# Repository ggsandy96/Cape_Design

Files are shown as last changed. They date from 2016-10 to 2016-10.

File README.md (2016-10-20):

# Cape_Design
The Cape for beagle bone has the options for ADC to BBB till 24V and an power controller circuit, with reverse polarity protection and over voltage protection. Apart from these, there was an interrupt generator, which generates an interrupt when the power goes off and BBB shifts to battery power

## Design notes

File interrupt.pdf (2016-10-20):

Installations:

1. sudo apt-get install git
2. git clone https://github.com/derekmolloy/exploringBB.git
3. cd exploringBB/extras/kernel/gpio_test

Replace gpio_test.c with the new ‘gpio_test.c’ sent.

4. make
5. sudo insmod gpio_test.ko

The interrupt program will be installed in the kernel.

Program:

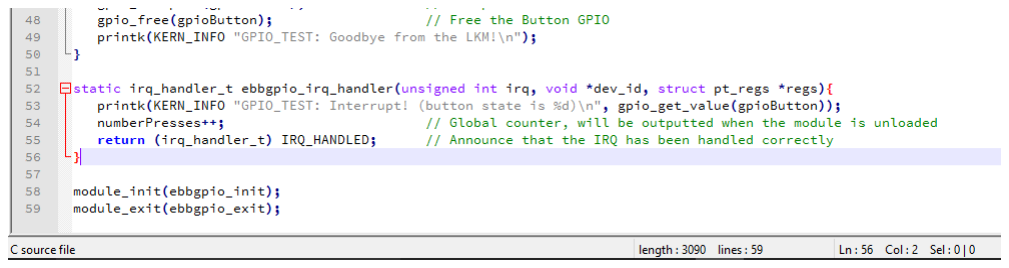
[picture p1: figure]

The things inside the function can be edited and used as per what the interrupt has to do.

Only this function needs to be edited and built.

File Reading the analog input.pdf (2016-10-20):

# READING THE ANALOG INPUT

EXPORT ANALOG INPUT PORTS

echo cape-bone-iio > /sys/devices/bone_capemgr.*/slots

READING THE VALUE

find /sys/ -name ‘*AIN*’

/sys/devices/ocp.2/helper.14/AIN0

/sys/devices/ocp.2/helper.14/AIN1

/sys/devices/ocp.2/helper.14/AIN2

/sys/devices/ocp.2/helper.14/AIN3

/sys/devices/ocp.2/helper.14/AIN4

/sys/devices/ocp.2/helper.14/AIN5

/sys/devices/ocp.2/helper.14/AIN6

/sys/devices/ocp.2/helper.14/AIN7

cd /sys/devices/ocp.2/helper.14

cat AIN1

******* This will show the analog value of the pin*******

0.1V = 100 as per the value shown

So, the value shown divided by 1000, multiplied and rescaled to 24V

1800 = 24V

1 = 24/1800

So, the value shown*24/1800

If value is 1000, then input voltage is

=1000*24/1800

=13.33 V

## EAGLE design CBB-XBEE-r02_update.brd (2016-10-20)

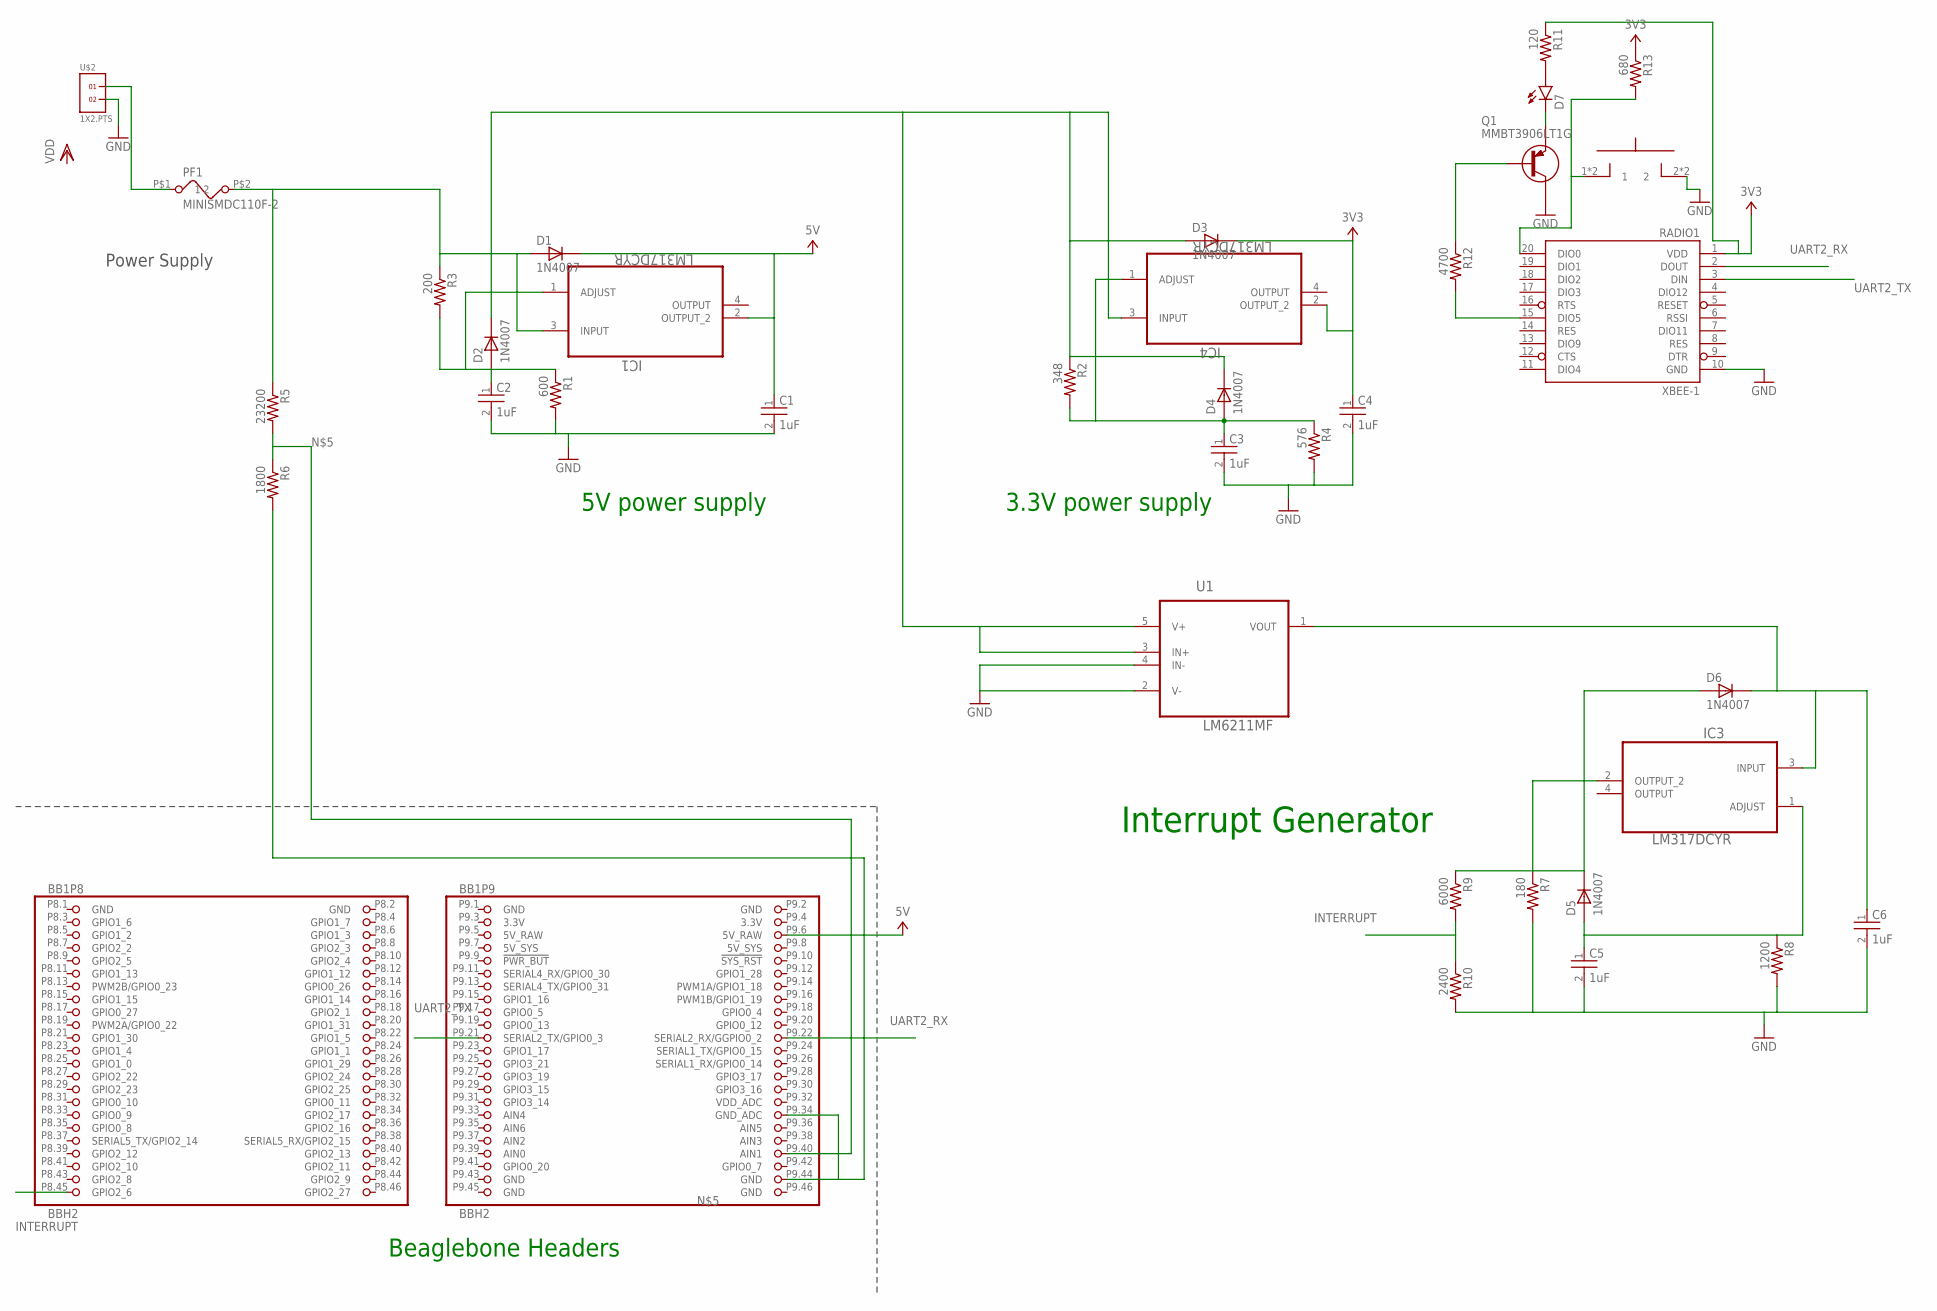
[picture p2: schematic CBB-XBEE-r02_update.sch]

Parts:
BB1: BBH2; BB_CAPE_TOP
C1, C2, C3, C4, C5, C6: 1uF; CAPC2012X135N
D1, D2, D3, D4, D5, D6: 1N4007; DIOAD1070W78L465D235P
D7: LED3MM
IC1, IC3, IC4: LM317DCYR; SOT230P700X180-4N
PF1: MINISMDC110F-2; MINISMDC110
Q1: MMBT3906LT1G; SOT23
R1: 600; 0603-RES
R2: 348; 0603-RES
R3: 200; 0603-RES
R4: 576; 0603-RES
R5: 23200; 0603-RES
R6: 1800; 0603-RES
R7: 180; 0603-RES
R8: 1200; 0603-RES
R9: 6000; 0603-RES
R10: 2400; 0603-RES
R11: 120; 0603-RES
R12: 4700; 0603-RES
R13: 680; 0603-RES
RADIO1: XBEE-1; XBEE
U1: LM6211MF; SOT95P284X122-5N
U$1: SPST-NOKS-01Q-01; KS-01Q-01
U$2: 1X2.PTS; PTS.FIXED

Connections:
3.3V: BB1.P9.3 (3.3V), BB1.P9.4 (3.3V)
3V3: C4.1 (A), D3.C, IC4.2 (OUTPUT_2), R11.1, R13.1, RADIO1.1 (VDD)
5V: BB1.P9.6 (5V_RAW), C1.1 (A), D1.C, IC1.2 (OUTPUT_2)
5V_RAW: BB1.P9.5 (5V_RAW)
5V_SYS: BB1.P9.7 (5V_SYS), BB1.P9.8 (5V_SYS)
GND: BB1.P8.1 (GND), BB1.P8.2 (GND), BB1.P9.1 (GND), BB1.P9.2 (GND), C1.2 (C), C2.2 (C), C3.2 (C), C4.2 (C), C5.2 (C), C6.2 (C), Q1.3 (C), R1.2, R4.2, R7.2, R8.2, R10.2, RADIO1.10 (GND), U1.2 (V-), U1.4 (IN-), U$1.2, U$1.4 (2), U$2.2
INTERRUPT: BB1.P8.45 (GPIO2_6), R9.2, R10.1
unnamed: C3.1 (A), D4.A, IC4.1 (ADJUST), R2.2, R4.1
unnamed: D5.C, D6.A, IC3.2 (OUTPUT_2), R7.1, R9.1
unnamed: C2.1 (A), D2.A, IC1.1 (ADJUST), R1.1, R3.2
unnamed: BB1.P9.40 (AIN1), R5.2, R6.1
unnamed: R12.2, RADIO1.15 (DIO5)
unnamed: D1.A, D2.C, D3.A, D4.C, IC1.3 (INPUT), IC4.3 (INPUT), PF1.P$2 (2), R2.1, R3.1, R5.1, U1.3 (IN+), U1.5 (V+)
unnamed: Q1.1 (B), R12.1
unnamed: C5.1 (A), D5.A, IC3.1 (ADJUST), R8.1
unnamed: C6.1 (A), D6.C, IC3.3 (INPUT), U1.1 (VOUT)
unnamed: R13.2, RADIO1.20 (DIO0), U$1.1, U$1.3 (1)
unnamed: D7.A, R11.2
unnamed: D7.K (C), Q1.2 (E)
unnamed: PF1.P$1 (1), U$2.1
unnamed: BB1.P9.34 (GND_ADC), BB1.P9.44 (GND), R6.2
UART2_RX: BB1.P9.22 (SERIAL2_RX/GGPIO0_2), RADIO1.2 (DOUT)
UART2_TX: BB1.P9.21 (SERIAL2_TX/GPIO0_3), RADIO1.3 (DIN)

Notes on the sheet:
Power Supply
Beaglebone Headers
5V power supply
3.3V power supply
Interrupt Generator

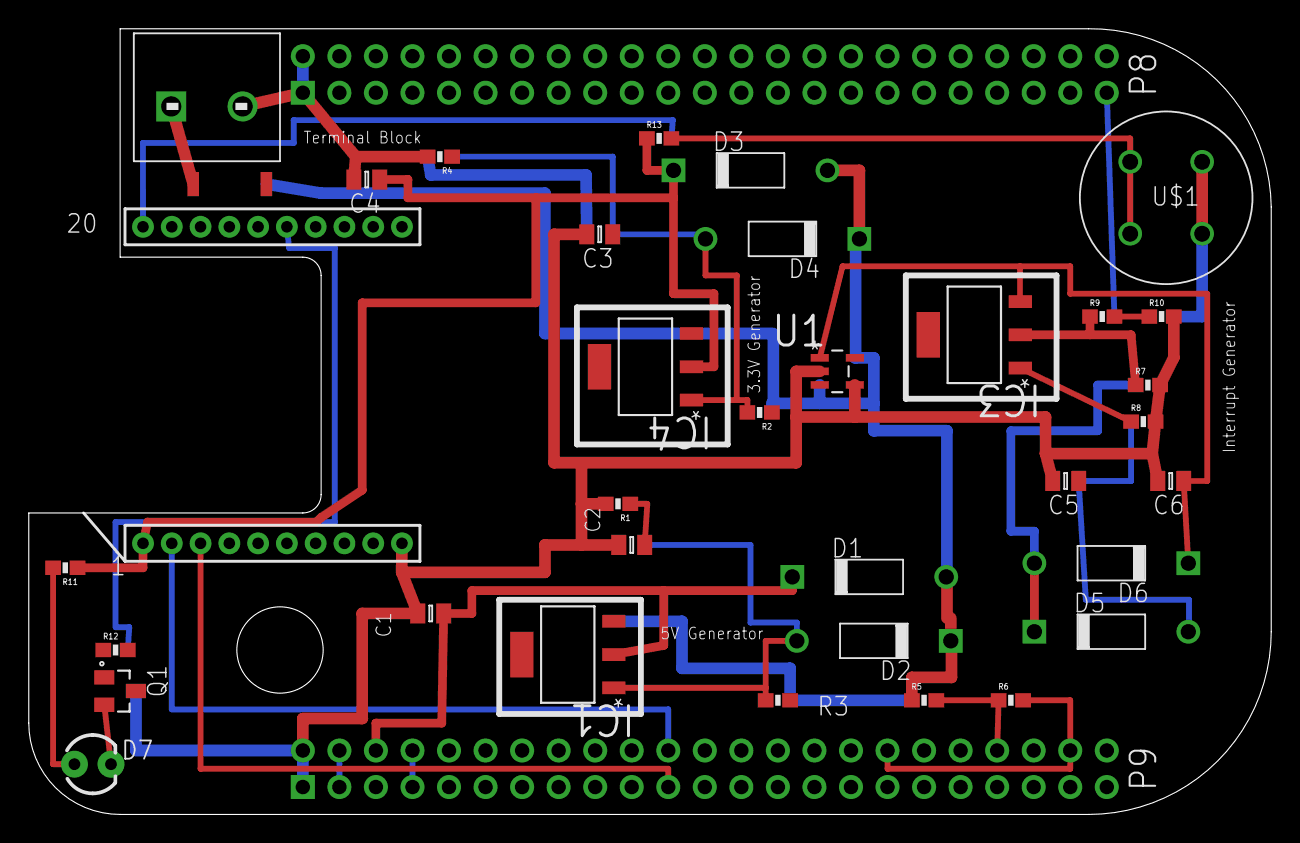
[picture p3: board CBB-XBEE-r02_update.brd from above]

Board: 2 copper layers, 86.4 x 54.6 mm, 36 parts (1 on the bottom side), 22 nets.

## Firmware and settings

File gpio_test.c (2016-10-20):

#include <linux/init.h>
#include <linux/module.h>
#include <linux/kernel.h>
#include <linux/gpio.h>                 // Required for the GPIO functions
#include <linux/interrupt.h>            // Required for the IRQ code
#include <stdio.h>

MODULE_LICENSE("GPL");
MODULE_AUTHOR("Goluguri Sandeep Reddy");
MODULE_DESCRIPTION("Interrupt Detector");
MODULE_VERSION("0.1");

static unsigned int gpioButton = 70;   ///< hard coding the button gpio for this example to P8_45 (GPIO70)
static unsigned int irqNumber;          ///< Used to share the IRQ number within this file
static unsigned int numberPresses = 0;  ///< For information, store the number of button presses

static irq_handler_t  ebbgpio_irq_handler(unsigned int irq, void *dev_id, struct pt_regs *regs);

static int __init ebbgpio_init(void){
   int result = 0;
   printk(KERN_INFO "INTERRUPT_TEST: Initializing the INTERRUPT_TEST \n");
   
   gpio_request(gpioButton, "sysfs");       // Set up the gpioButton
   gpio_direction_input(gpioButton);        // Set the button GPIO to be an input
   gpio_set_debounce(gpioButton, 0);      // Debounce the button with a delay of 0ms
   gpio_export(gpioButton, false);          // Causes gpio75 to appear in /sys/class/gpio

   printk(KERN_INFO "INTERRUPT_TEST: The button state is currently: %d\n", gpio_get_value(gpioButton));

   irqNumber = gpio_to_irq(gpioButton);
   printk(KERN_INFO "INTERRUPT_TEST: The button is mapped to IRQ: %d\n", irqNumber);

   result = request_irq(irqNumber,             // The interrupt number requested
                        (irq_handler_t) ebbgpio_irq_handler, // The pointer to the handler function below
                        IRQF_TRIGGER_FALLING,   // Interrupt on falling edge (button press, not release)
                        "ebb_gpio_handler",    // Used in /proc/interrupts to identify the owner
                        NULL);                 // The *dev_id for shared interrupt lines, NULL is okay

   printk(KERN_INFO "GPIO_TEST: The interrupt request result is: %d\n", result);
   return result;
}

static void __exit ebbgpio_exit(void){
   printk(KERN_INFO "GPIO_TEST: The button state is currently: %d\n", gpio_get_value(gpioButton));
   printk(KERN_INFO "GPIO_TEST: The button was pressed %d times\n", numberPresses);
   free_irq(irqNumber, NULL);               // Free the IRQ number, no *dev_id required in this case
   gpio_unexport(gpioButton);               // Unexport the Button GPIO
   gpio_free(gpioButton);                   // Free the Button GPIO
   printk(KERN_INFO "GPIO_TEST: Goodbye from the LKM!\n");
}

static irq_handler_t ebbgpio_irq_handler(unsigned int irq, void *dev_id, struct pt_regs *regs){
   printk(KERN_INFO "GPIO_TEST: Interrupt! (button state is %d)\n", gpio_get_value(gpioButton));
   numberPresses++;                         // Global counter, will be outputted when the module is unloaded
   return (irq_handler_t) IRQ_HANDLED;      // Announce that the IRQ has been handled correctly
}

module_init(ebbgpio_init);
module_exit(ebbgpio_exit);

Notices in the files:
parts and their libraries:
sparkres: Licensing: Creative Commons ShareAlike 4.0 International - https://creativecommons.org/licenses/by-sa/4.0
